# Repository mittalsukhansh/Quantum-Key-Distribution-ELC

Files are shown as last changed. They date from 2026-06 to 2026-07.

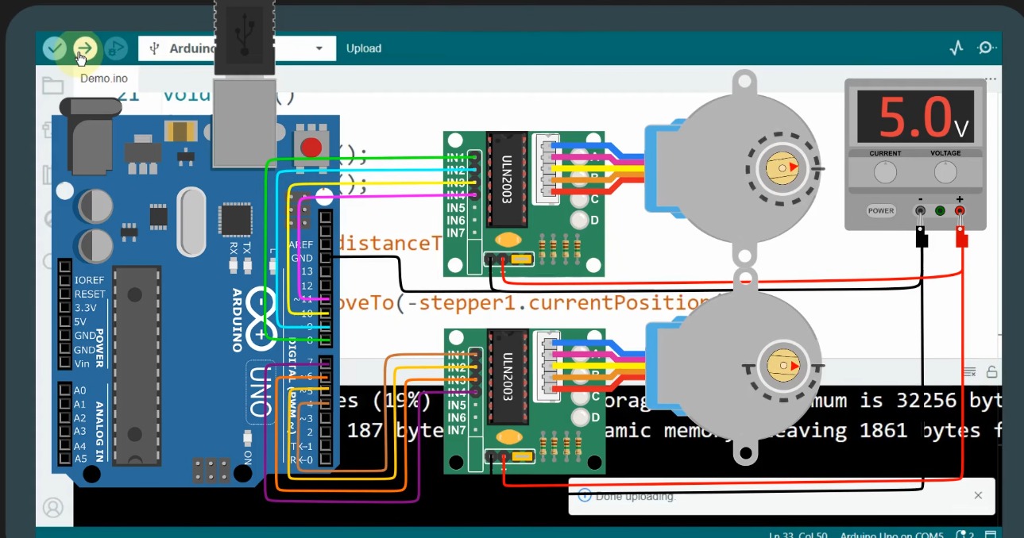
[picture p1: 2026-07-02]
codes/connection_setup.jpeg

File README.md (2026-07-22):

# Quantum-Key-Distribution-ELC

# Low-Cost Quantum Key Distribution (QKD) Simulator using Photonic Communication

**Project 19**

Supervised by: Dr. G.V. Eswara Rao & Dr. Subhrendu Chattopadhyay

Repository: [mittalsukhansh/Quantum-Key-Distribution-ELC](https://github.com/mittalsukhansh/Quantum-Key-Distribution-ELC)

---

## Overview

This project implements a low-cost, hardware-based simulator for **Quantum Key Distribution (QKD)** using photonic (optical) communication. QKD is a method for securely exchanging cryptographic keys using quantum states of light (photons). Its security is guaranteed by the laws of quantum mechanics rather than computational hardness — any attempt at measurement/eavesdropping disturbs the quantum state and introduces detectable errors. This makes QKD **information-theoretically secure**, as opposed to the computationally-secure schemes used in classical cryptography.

## How It Works

**Security Principle:** Any interception changes photon polarization/phase and introduces detectable errors.

**Goal:** Generate symmetric secret keys for encryption with provable detection of eavesdropping.

**QKD Workflow:**
1. Prepare quantum states
2. Transmit photons
3. Measure in chosen bases
4. Sift key
5. Estimate error rate
6. Apply error correction & privacy amplification

**Channel:** Implemented over free-space optical links (photonic communication); sensitive to loss and noise.

## Protocol: BB84

The system implements the **BB84 protocol** (Bennett & Brassard, 1984) — the canonical QKD protocol, using two conjugate polarization bases (rectilinear & diagonal).

1. **State Preparation** – Alice prepares photons in one of four polarization states {0°, 45°, 90°, 135°}, representing bits and bases.
2. **Measurement & Sifting** – Bob measures each photon in a randomly chosen basis; Alice and Bob then publicly compare bases and discard mismatched measurements.
3. **Error Estimation** – A subset of the sifted key is sampled to estimate the Quantum Bit Error Rate (QBER). A high QBER indicates eavesdropping or channel/hardware issues.
4. **Post-Processing** – Error correction (e.g., CASCADE/LDPC) and privacy amplification are applied to produce the final secure key.

**Real-world applications:** Banking & Finance, Government & Defence, Telecom & Backbone Links, Cloud & Data Centres.

## Hardware Architecture

### Transmitter (Alice)
- Laser diode
- Arduino UNO
- LED
- 3D-printed polarizer assembly + stepper motor
- Firmware: [`transmitter.txt`](./transmitter.txt)

### Receiver (Bob)
- Photodiode (BPW32/BPW34)
- 100 V potentiometer
- Resistors
- Op-amp (LM358)
- ESP32 (v1)
- Firmware: [`reciever.c`](./reciever.c)

### Stepper Motors & Polarizers
- Stepper motors rotate 3D-printed polarizer mounts to switch between the four BB84 polarization bases programmatically.
- A custom gear train (motor gear + driven gear on the polarizer holder) provides a precise, repeatable angular step for each basis change.
- Firmware synchronizes motor rotation on the TX side with analyzer rotation on the RX side for every transmitted bit.
- Gear reduction improved angular accuracy beyond the stepper motor's native step resolution, reducing polarization-alignment error.

### Wiring
See [`connection_setup_wire.jpeg`](./connection_setup_wire.jpeg) for the full TX/RX wiring diagram.

## Mechanical Design (3D-Printed Parts)

To reduce cost and improve repeatability, all mechanical parts were custom-designed and 3D-printed using a CAD-driven, iterative design process. Designs are in [`cad/`](./cad).

| Part | Purpose |
|---|---|
| Gears | Transfer precise rotational motion from the stepper motor to the polarizer disc |
| Gear Holders | Keep gears aligned and meshed correctly so rotation stays smooth and slip-free |
| Enclosures (laser & receiver) | Shield the laser diode and photodiode from ambient light and dust, keeping the optical path clean and consistent |
| Base plate & height elevator | Provide a stable, aligned mounting platform for TX/RX components |

Material: **PLA**, chosen for dimensional stability and ease of printing.

## Challenges & Solutions

### Transmitter / Receiver
| Challenge | Solution |
|---|---|
| Unstable timing at low pulse rates causing missed detections | Slowed and fine-tuned code timing so each bit had sufficient read time |
| Laser beam missing the BPW32 detector (alignment drift) | Built a shoebox enclosure with a precisely measured hole to align the beam onto the sensor |
| Receiver unreliable at lower bit rates (timing drift/misreads) | Optimized firmware timing between samples |
| Difficulty identifying a reliable ON/OFF detection threshold under varying light | Repeatedly tested the circuit and manually tuned the threshold using live sensor readings — see [`01_BPW32_ADC_Test.ino`](./01_BPW32_ADC_Test.ino) and [`02_OOK_Detection.ino`](./02_OOK_Detection.ino) |

### 3D Printing
| Challenge | Solution / Notes |
|---|---|
| Lab 3D printer became unreliable mid-build | Reprinted affected parts; adjusted build schedule |
| Achieving tight tolerances | Careful measurement using vernier calipers and screw gauges |
| Material selection | Chose PLA for the best balance of stiffness and printability |

### Stepper Motors & Polarizers
| Challenge | Solution / Result |
|---|---|
| Friction & wear causing step loss | Mechanical adjustments to the gear train |
| Flexible mounts causing misalignment | Improved mounting surface rigidity |
| Steps-per-degree varying under load | Calibration tuning |

**Result:** After mechanical and firmware adjustments, repeatability improved to within acceptable alignment tolerances for experimental QKD demonstration at reduced bit rates.

## Key Learnings

1. **Quantum Cryptography Fundamentals** – How qubits, polarization encoding, and the BB84 protocol combine to enable provably secure key exchange.
2. **Photonics & Hardware Precision** – The importance of exact alignment and timing when working with lasers, polarizers, and photodiodes in a real optical setup.
3. **Mechanical Design & Prototyping** – Practical skills in 3D printing, precise measurement, and iterative design to solve real hardware integration problems.
4. **Embedded Systems Debugging** – Hands-on experience tuning code timing and detection thresholds to make a real-time system work reliably under changing conditions.

## References

- B. A. Forouzan, *Data Communications and Networking*, 5th ed. New York, NY: McGraw-Hill Education, 2013.
- BB84 Protocol
- Photodiode (BPW32/BPW34) datasheet
- Stepper motor datasheet
- Full build documentation: [`QKD-Kit-Development.pdf`](./QKD-Kit-Development.pdf)

---

## Repository Structure
```
.
├── Daily loger/                 # Build/testing logs kept during development
├── cad/                         # 3D-printable part designs (gears, holders, enclosures, base plate)
├── codes/                       # Additional firmware / support code
├── 01_BPW32_ADC_Test.ino        # Arduino sketch: raw ADC test on the BPW32 photodiode
├── 02_OOK_Detection.ino         # Arduino sketch: On-Off Keying (OOK) detection logic
├── reciever.c                   # Receiver (Bob / ESP32) firmware
├── transmitter.txt              # Transmitter (Alice / Arduino UNO) firmware
├── connection_setup_wire.jpeg   # TX/RX wiring diagram
├── Inventory                    # Bill of materials / component inventory
├── QKD-Kit-Development.pdf      # Full project report / build documentation
└── README.md
```

## Getting Started

1. **Bill of materials** – check [`Inventory`](./Inventory) for the full component list.
2. **Wiring** – follow [`connection_setup_wire.jpeg`](./connection_setup_wire.jpeg) to connect the laser/Arduino UNO (TX) and photodiode/ESP32 (RX).
3. **Mechanical build** – 3D-print the parts in [`cad/`](./cad) (PLA recommended) and assemble the gear train, polarizer mounts, and enclosures.
4. **Firmware**
   - Flash [`transmitter.txt`](./transmitter.txt) (rename to `.ino` as needed) to the Arduino UNO for the transmitter.
   - Flash [`reciever.c`](./reciever.c) to the ESP32 for the receiver.
   - Use [`01_BPW32_ADC_Test.ino`](./01_BPW32_ADC_Test.ino) to verify the photodiode is reading correctly before running full detection.
   - Use [`02_OOK_Detection.ino`](./02_OOK_Detection.ino) to test On-Off Keying detection and threshold tuning.
5. **Reference** – see [`QKD-Kit-Development.pdf`](./QKD-Kit-Development.pdf) for the complete build walkthrough.

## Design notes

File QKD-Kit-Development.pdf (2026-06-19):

# Low Cost Quantum Key Distribution (QKD) Simulator using Photonic Communication

Presented By
Dr. G.V. Eswara Rao
&
Dr. Subhrendu Chattopadhyay

# Why Quantum Key Distribution?

- Current Problem
- Classical cryptography relies on computational hardness
- Future quantum computers threaten RSA and ECC
- Sensitive communications require long-term security
- QKD Solution
- Uses principles of quantum mechanics
- Eavesdropping changes quantum states
- Enables secure key exchange with intrusion detection
- Real-World Applications
- Banking and financial networks
- Government communication
- Defense communication systems
- Critical infrastructure
- Data center interconnects

# Quantum Key Distribution (QKD)

### - What is QKD?

- QKD is a secure communication method that uses quantum states to distribute cryptographic keys.

### - Core Principles

- Photons carry information
- Quantum measurement disturbs state
- No-cloning theorem prevents copying
- Eavesdropping becomes detectable

## QKD over Photonic Communication

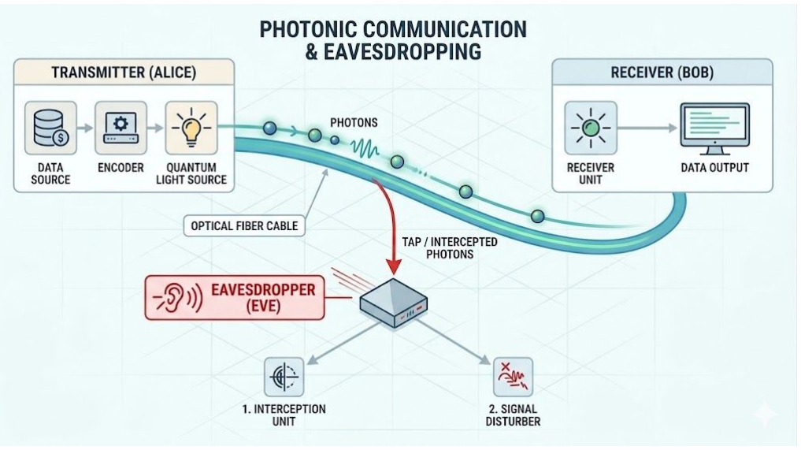
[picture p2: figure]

## QKD over Photonic Communication

### 1. Photons Carry Information

- A photon is a tiny packet of light energy. In quantum communication, photons are used as the “messengers” that carry information from Alice to Bob
- In normal digital communication:
- bits are represented using voltage levels, such as 0 V and 5 V.
- In quantum photonic communication:
- bits are represented using quantum properties of photons,
- especially polarization
- Polarization as Information
- A photon’s electric field can oscillate in different directions.
- For example:
| Polarization | Meaning
- | Horizontal | Bit 0
- VerticalBit 1
- | 45° | Bit 0 in diagonal basis
- | 135° | Bit 1 in diagonal basis
- Thus, information is encoded into photon states.

## QKD over Photonic Communication

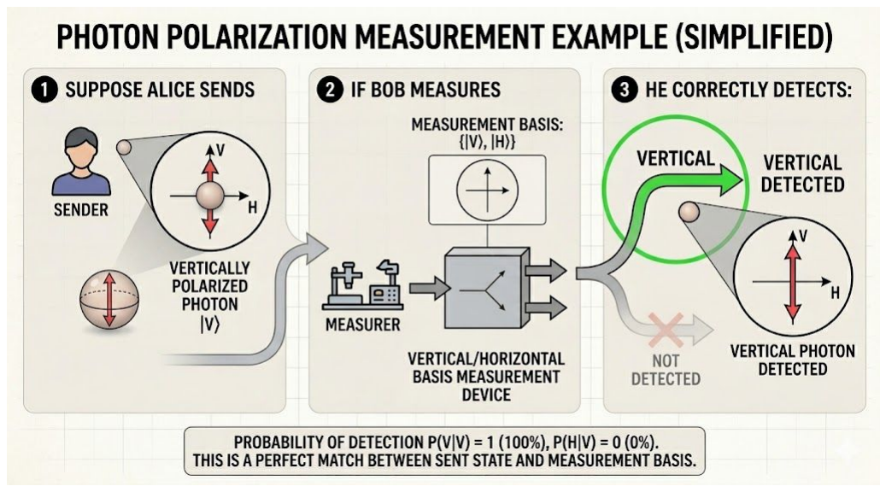
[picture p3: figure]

- But in quantum systems:
measurement itself changes the quantum state
- Example with Polarization Suppose Alice sends: a vertically polarized photon
If Bob measures using:
vertical/horizontal basis, he correctly detects: Vertical

### 2. Quantum Measurement Disturbs the State

- This is one of the most important ideas in quantum mechanics
- In classical systems: you can measure something without changing it

## QKD over Photonic Communication

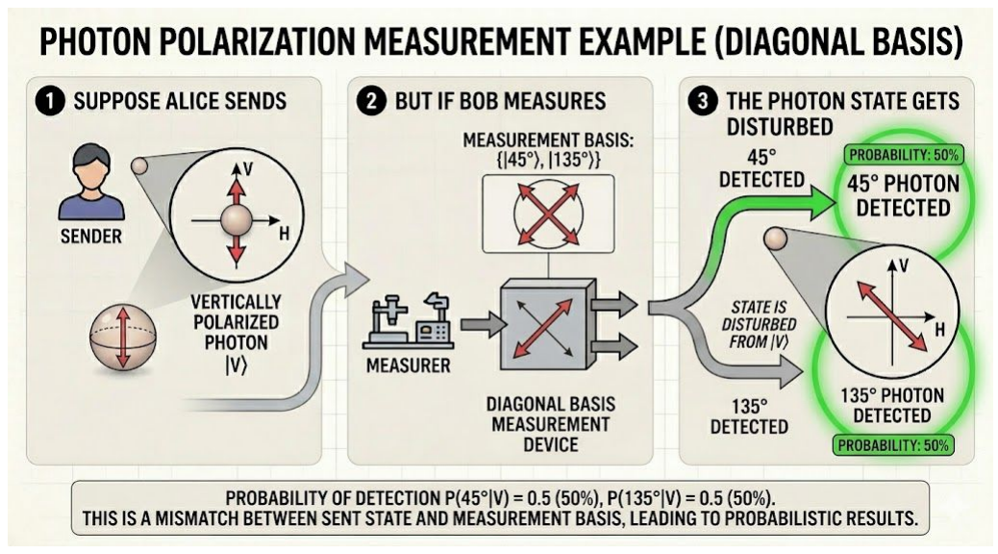
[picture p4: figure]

- But in quantum systems: measurement itself changes the quantum state
- Example with Polarization
Suppose Alice sends: a vertically polarized photon
But if Bob measures using: diagonal basis, the photon state gets disturbed. Now the result becomes
probabilistic:sometimes 45°, sometimes 135°

### 2. Quantum Measurement Disturbs the State

- This is one of the most important ideas in quantum mechanics.
- In classical systems: you can measure something without changing it.

## QKD over Photonic Communication

### 2. Quantum Measurement Disturbs the State

- Why This Happens
- Quantum particles do not always have fixed classical properties before measurement
- Measurement “forces” the system into one of the allowed outcomes
- This process is called: Wave function collapse
- Importance in QKD
- This property creates security. If Eve tries to measure photons: she may choose wrong basis, measurement disturbs the photon, errors appear in Bob’s received bits. Thus:spying changes the communication

## QKD over Photonic Communication

### 3. No-Cloning Theorem Prevents Copying

### - In classical communication: data can be copied perfectly. For Example: copying a file, duplicating

packets, forwarding emails.

### - But in quantum mechanics:

- an unknown quantum state cannot be copied perfectly. This is called: No-Cloning Theorem

## QKD over Photonic Communication

### 3. No-Cloning Theorem Prevents Copying - Intuition

- Suppose Eve intercepts a photon. She wants to: keep a copy and send another identical copy to Bob.
- Quantum mechanics does not allow perfect duplication of an unknown quantum state.
- Why?
- A quantum state may exist in:
- superposition, unknown polarization, probabilistic form.
- And Copying would require: measuring it exactly first. But measurement itself disturbs the state. So perfect copying becomes impossible.

## QKD over Photonic Communication

### 3. No-Cloning Theorem Prevents Copying

### - Security Benefit

- This is a major reason QKD is secure.
- Eve cannot: secretly duplicate photons, store copies, and later analyze them.
- She must interact with the original photon, which introduces detectable errors..

## QKD over Photonic Communication

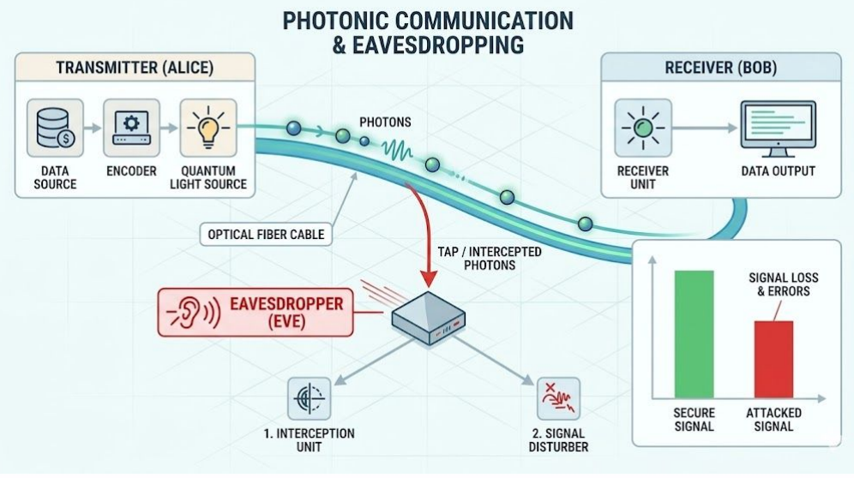
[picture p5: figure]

## QKD over Photonic Communication

Spying leaves evidence.
- How Eve Causes Errors: Suppose Alice sends Vertical polarization and Eve intercepts it. But Eve does not know the correct basis
- | Case 1: Eve Chooses Correct Basis: | She measures correctly. No error introduced.
- | Case 2: Eve Chooses Wrong Basis: | Measurement disturbs photon state.
- When Bob later measures: he may get wrong result.
- Thus: error rate increases.
- Quantum Bit Error Rate (QBER): Alice and Bob compare a small subset of bits publicly. If too many mismatches occur: they conclude: Possible eavesdropping detected
- | Example: | Transmission | Error Rate
| Without Eve: | Normal | Very low
| With Eve: | Intercept-resend attack | High
- Why is this Revolutionary?
- Traditional security depends on: computational difficulty
- Quantum security depends on: laws of physics. That makes QKD fundamentally different from classical cryptography

# Basics of Photonic Communication

## Photonic/Optical Communication

### - Components:

- Transmitter: LED or Laser source
- Channel: Optical fiber or free-space optical link
- Receiver: Photodiode (PIN/APD) converts light to electrical signals
- Signal processing and decoding

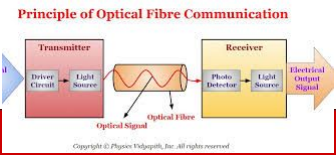
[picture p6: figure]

## Signal Processing in Photonic Communication?

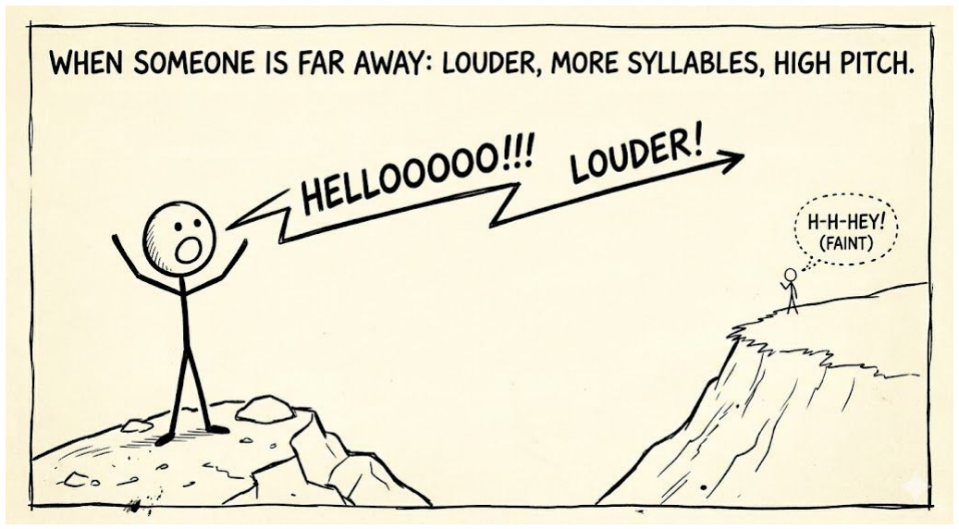
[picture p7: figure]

Think if someone is far away. What do you do? You use modulation and coding. What type of modulation is used in this figure?

## Photonic/Optical Communication

### - How Information is carried:

- Digital encoding to increase data rate.
- Analogue modulation to avoid fading

# Why Coding in Communication?

### - Coding Schemes allows more data embedding in each signal element. Same as use of “more

syllables”.

### - Schemes:

- NRZ
- RZ
- Manchester …

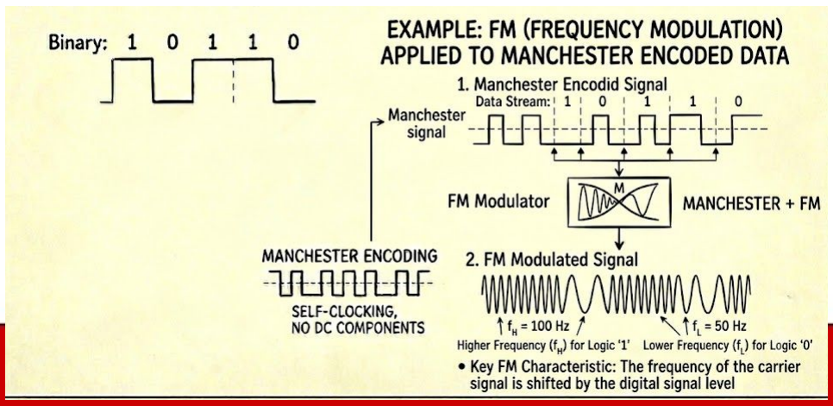
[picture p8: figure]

# Why Coding in Communication?

### - Coding Schemes allows more data embedding in each signal element. Same as use of “more

syllables”.

### - Schemes:

- NRZ
- RZ
- Manchester …

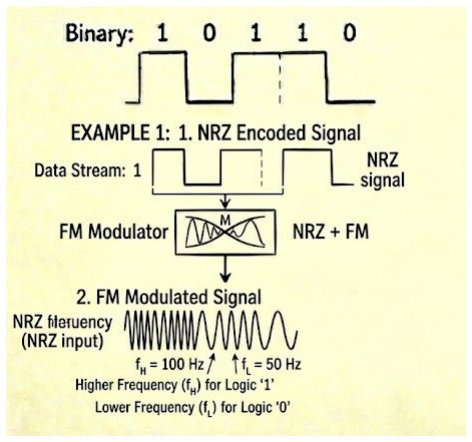
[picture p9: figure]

# Coding Schemes in Photonics

Scheme | Main Advantage | Main Disadvantage
NRZ | Minimum bandwidth | Poor synchronization
RZ | Better synchronization | Higher bandwidth required
Manchester | Self-clocking | Highest bandwidth required

## Why Modulation in Communication?

### - Allows smaller antennas - Enables long-distance transmission - Prevents signal mixing (interference) - Improves signal quality and reduces noise - Supports multiplexing - Efficient use of bandwidth

L≈ (λ/4) = (c/4f)
where: L = antenna length; λ = wavelength; c = speed of light; f = frequency

## Why Modulation in Communication?

### - Allows smaller antennas - Enables long-distance transmission - Prevents signal mixing (interference) - Improves signal quality and reduces noise - Supports multiplexing - Efficient use of bandwidth

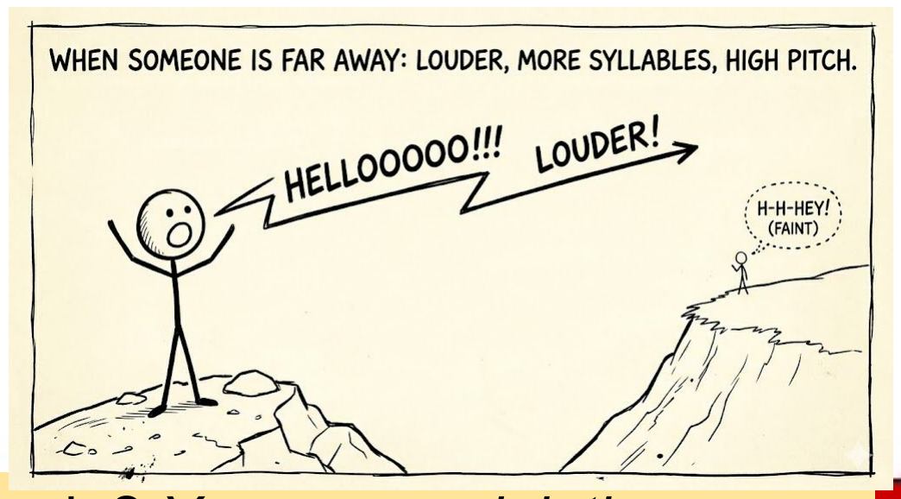
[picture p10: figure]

Think if someone is far away. What do you do? You use modulation. What type of modulation is used in this figure?

## Modulation and Coding Scheme

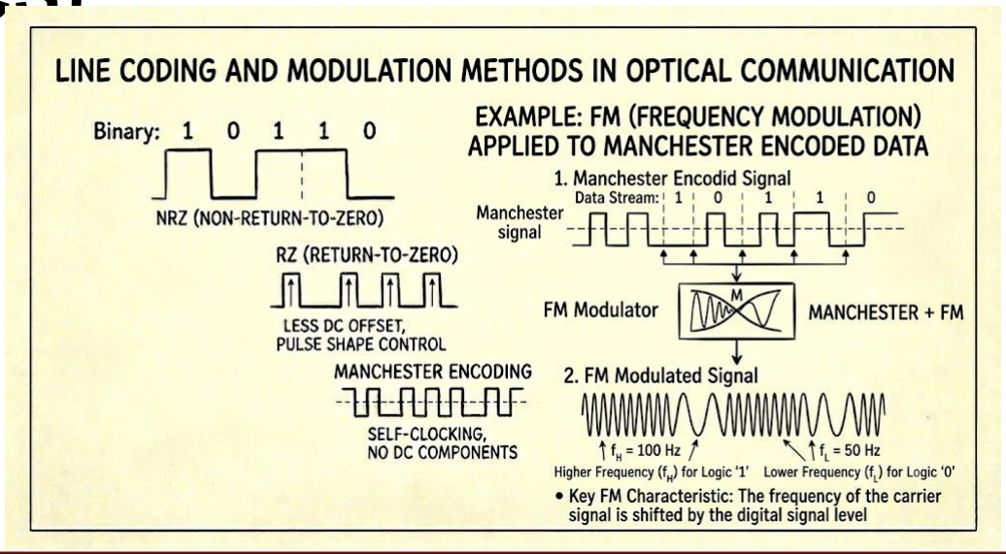
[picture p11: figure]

# (MCS)

## Photonic/Optical Communication

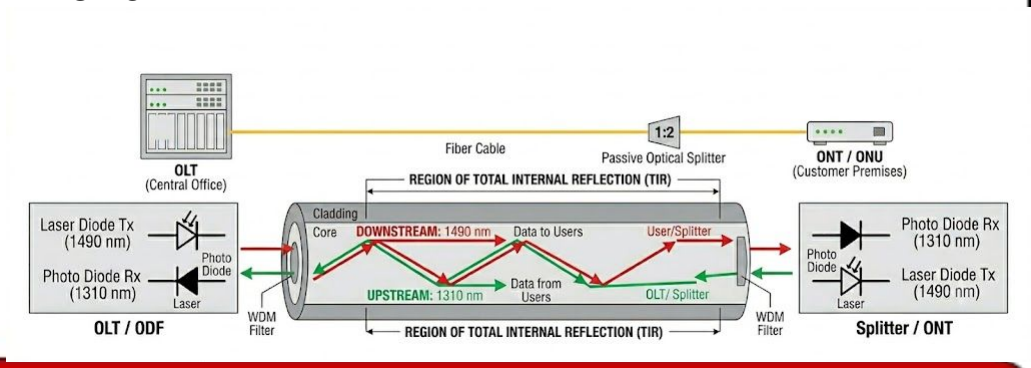
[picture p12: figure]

https://www.cisco.com/c/en/us/products/collateral/interfaces-modules/transceiver-modules/datasheet-c 78-736392.html (https://www.cisco.com/c/en/us/products/collateral/interfaces-modules/transceiver-modules/datasheet-c78-736392.html)

- Modulation: Intensity, Phase, Frequency
- Digital data represented by optical pulses

### - Modulation:

- Wavelength Division Multiplexing (WDM) ⇒ FDM
- Used in GPON Gateways for Duplex communication
- | TX: 1490 nm; | Rx: 1310 nm

# Basics of TCP/IP Stack

# TCP/IP Protocol Stack

https://en.wikipedia.org/wiki/Internet_protocol_suite

- The TCP/IP protocol stack (also known as the Internet Protocol Suite) is the conceptual framework and set of rules that allows computers to communicate over a network, including the global Internet.
- It breaks the complex process of moving data across the world into a modular, 4-layer stack. As data moves down the stack on the sender's side, each layer adds its own formatting header (encapsulation). When it arrives at the receiver, the process reverses (decapsulation).

+----------------------+
| Application | |
| HTTP, MQTT, DNS | |
+----------------------+
| Transport | |
| TCP, UDP | |
+----------------------+
| Internet | |
| IP, ICMP | |
+----------------------+
| Data Link | |
| 802.11 MAC, Ethernet |
+----------------------+
| Physical | |
| RF, Fiber, Copper | |
+----------------------+

# TCP/IP Protocol Stack

Development of full stack will be difficult.

Therefore, we’ll create a
smaller stack like this.

Components required:

+---------------------------------+
| Application Layer | |
| Text / Files / Commands | |
+---------------------------------+
| Data Link Layer | |
| Framing + CRC + ACK | |
+---------------------------------+
| Physical Layer | |
| NRZ encoding, | |
| OOK modulation, | |
| TX: Laser Driver, | |
| RX: BPW32 + TIA | |
+---------------------------------+

# Our Goal

## Our Setup: Hardware Requirement

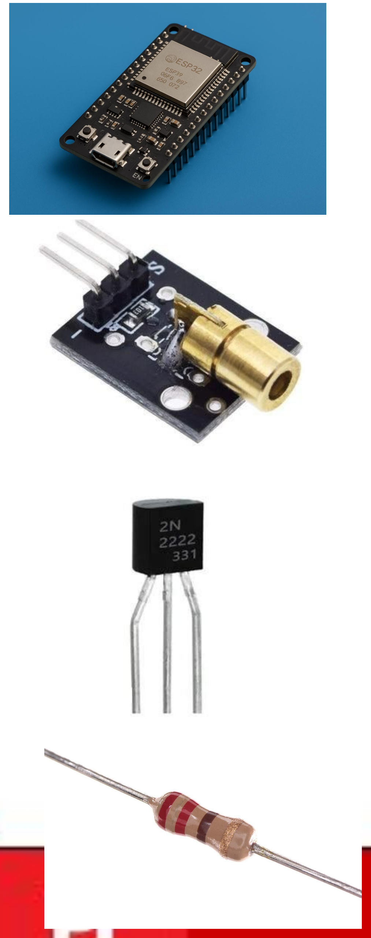
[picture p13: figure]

Components required: for TX

ESP32 DevKit → Controller
Laser Diode Module → Optical transmitter
NPN Transistor (2N2222/BC547) → Laser driver 220Ω–1kΩ Resistor → Transistor bias Breadboard/PCB → Prototyping
Power Supply (5V) → Laser power

## Our Setup: Hardware Requirement

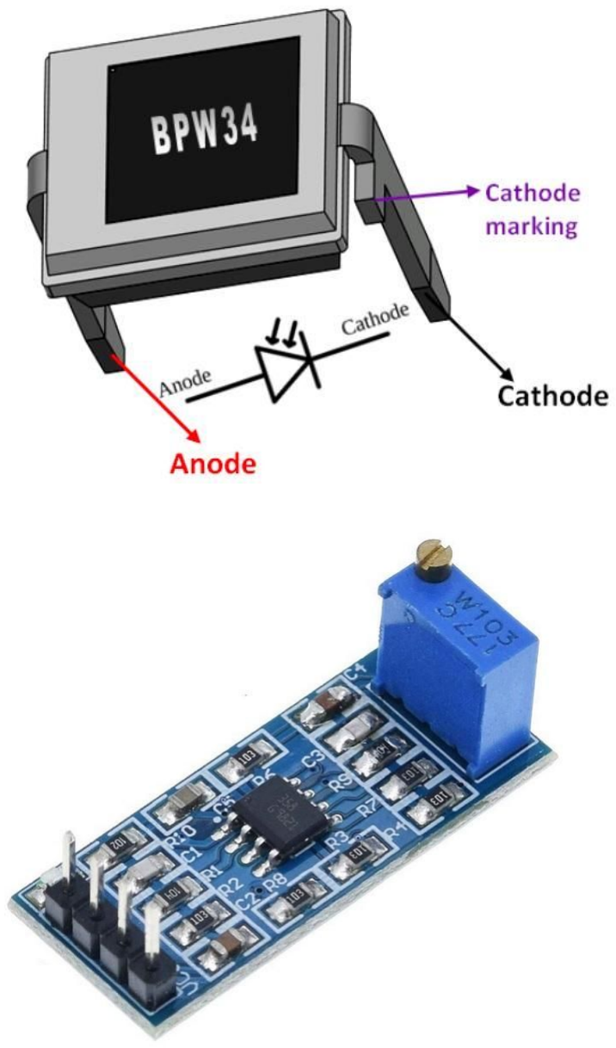
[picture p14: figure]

Components required: for RX

ESP32 DevKit → Controller
Breadboard/PCB → Prototyping Power Supply (5V) → Laser power
BPW32 Photodiode → Optical detector
LM393 Comparator → Digital slicing
Feedback Resistors (100kΩ–1MΩ) → Gain setting Capacitors (10pF–100nF) → Stability/filtering

## Our Setup: Software Requirement

Complete TX Call Flow

app_send_text()
│
└── mac_send()
│
├── create_frame()
├── append_crc()
│
└── phy_send_frame()
│
├── NRZ_encode()
├── ook_modulate()
│
└── laser_set()

+---------------------------------+
| Application Layer | |
| Text / Files / Commands | |
+---------------------------------+
| Data Link Layer | |
| Framing + CRC + ACK | |
+---------------------------------+
| Physical Layer | |
| NRZ encoding, | |
| OOK modulation, | |
| TX: Laser Driver, | |
| RX: BPW32 + TIA | |
+---------------------------------+

# TCP/IP Protocol Stack

Complete RX Call Flow

application_receive()
▲
└─ mac_receive()
│
├── crc_verify()
├── extract_payload()
▲
└── phy_receive_frame()
│
├── NRZ_decode()
├── ook_demodulate()
▲
└── bpw32_read()

+---------------------------------+
| Application Layer | |
| Text / Files / Commands | |
+---------------------------------+
| Data Link Layer | |
| Framing + CRC + ACK | |
+---------------------------------+
| Physical Layer | |
| NRZ encoding, | |
| OOK modulation, | |
| TX: Laser Driver, | |
| RX: BPW32 + TIA | |
+---------------------------------+

# TCP/IP Protocol Stack

+------------------------+
| Application Layer | |
| application_receive() | |
+------------------------+
| MAC Layer | |
| mac_receive() | |
| ├─ crc_verify() | |
| └─ extract_payload() | |
+------------------------+
| PHY Layer | |
| phy_receive_frame() | |
| ├─ manchester_decode() | | └─ ook_demodulate() |
+------------------------+
| Driver Layer | |
| bpw32_read() | |
+------------------------+
| Hardware | |
| BPW32 + TIA | |
+------------------------+

+------------------------+
| Application Layer | |
| application_send() | |
+------------------------+
| MAC Layer | |
| mac_send() | |
| ├─ create_header() | |
| ├─ add_payload() | |
| ├─ calculate_crc() | |
| └─ add_preamble() | |
+------------------------+
| PHY Layer | |
| phy_send_frame() | |
| ├─ manchester_encode() |
| ├─ ook_modulate() | |
| └─ symbol_timing() | |
+------------------------+
| Driver Layer | |
| laser_set() | |
| laser_enable() | |
| timer_start() | |
+------------------------+
| Hardware | |
| Laser Driver Circuit | |
| Laser Diode | |
+------------------------+
TX | RX

# Important Tutorials

# Tutorials

- Lec05: Digital Communication for Optical Communication
- https://www.youtube.com/watch?v=j0c9xHWtATo
- Arduino Photodiode Light Sensor (BPW34) Circuit &amp; Code Example. Arduino Photodiode Circuit Example For light intensity measurement (BPW34)"
- https://deepbluembedded.com/arduino-photodiode-light-sensor-bpw34-circuit-code-example/ (https://deepbluembedded.com/arduino-photodiode-light-sensor-bpw34-circuit-code-example/)
- Li - fi communication system using ON OFF Keying (OOK)
- https://www.youtube.com/watch?v=Aj9jUR7Xog8
- 28BYJ-48 Stepper Motor with ULN2003 & Arduino | Full Step vs
Half Step
- https://www.youtube.com/watch?v=uJriwdnPUD4
- Quantum cryptography: The BB 84 protocol (U3-02-03)
- https://www.youtube.com/watch?v=2kdRuqvIaww

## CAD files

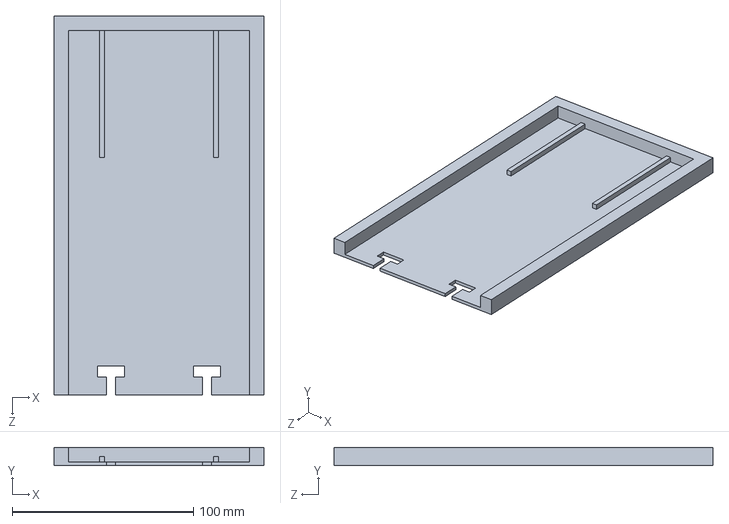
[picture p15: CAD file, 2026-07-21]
cad/Base Plate/Base tray part 1.SLDPRT
116.0 x 10.0 x 209.2 mm

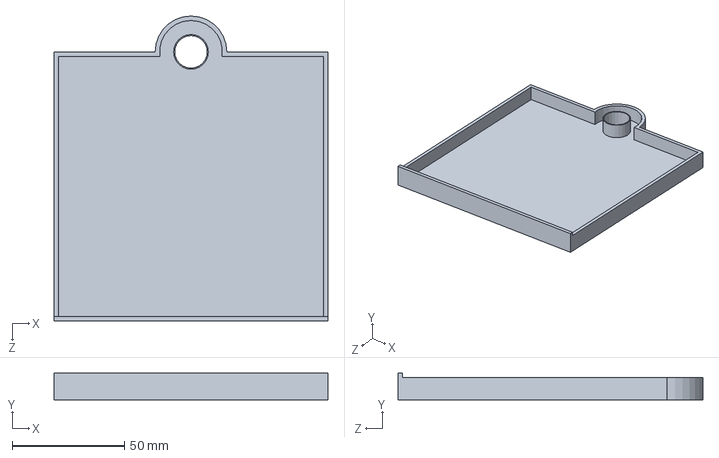
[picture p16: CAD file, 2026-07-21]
cad/gear/Gear holder2.SLDPRT
122.0 x 12.0 x 136.0 mm

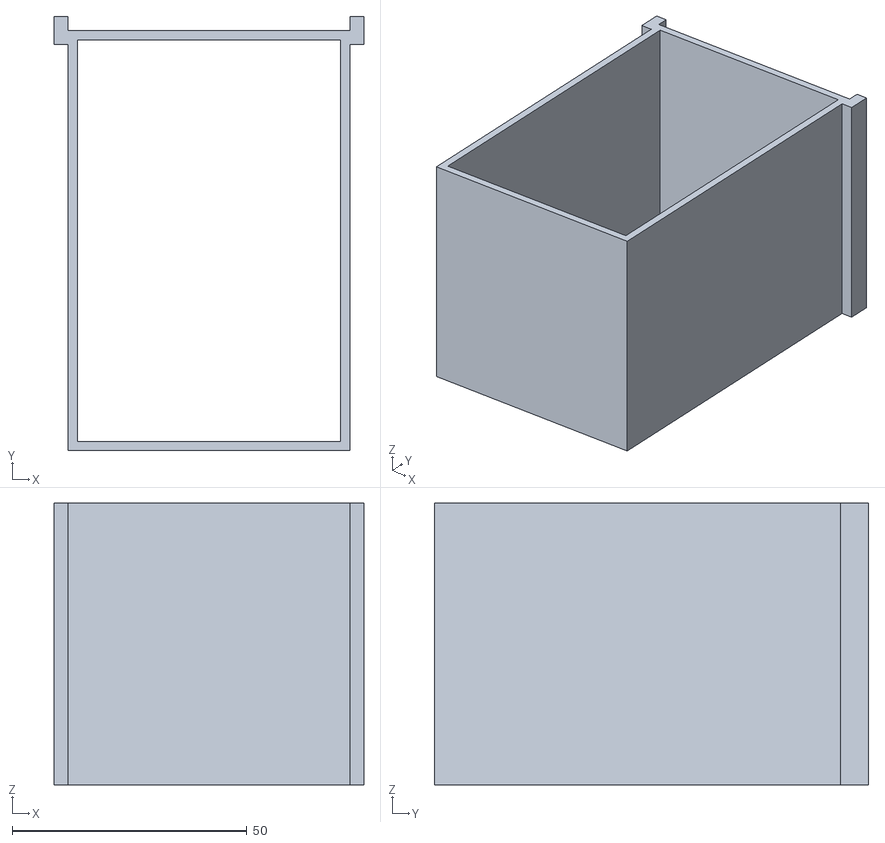
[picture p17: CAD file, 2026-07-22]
cad/Height adjusters/Reciever height stl.STL
66.0 x 92.5 x 60.0

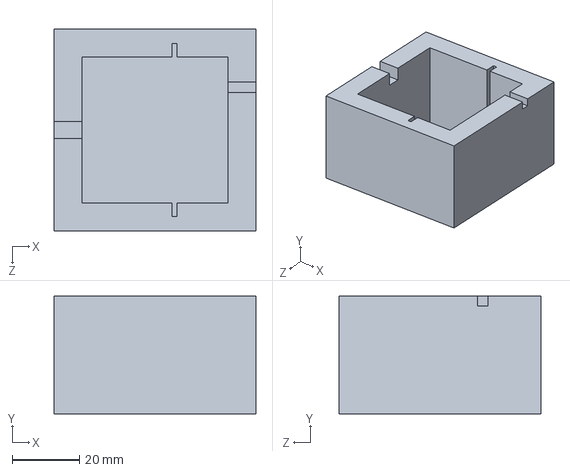
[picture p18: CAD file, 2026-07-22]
cad/LED AND RECIEVER/Part2.SLDPRT
60.0 x 35.0 x 60.0 mm

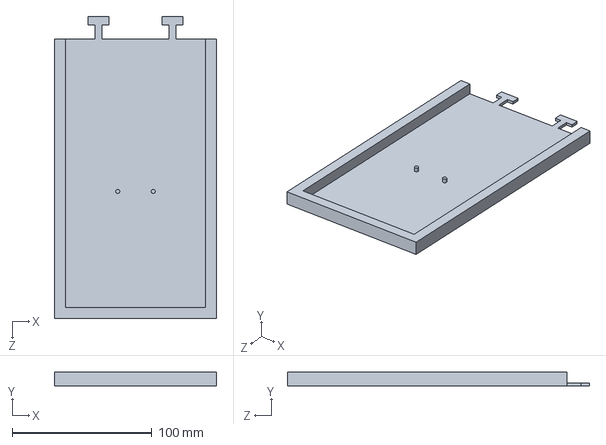
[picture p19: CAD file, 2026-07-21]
cad/Base Plate/base tray 2.SLDPRT
116.0 x 10.0 x 216.0 mm

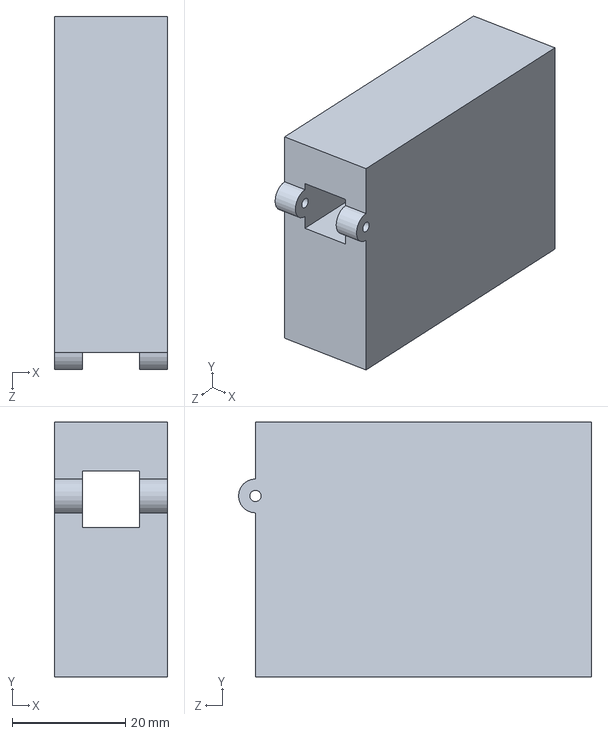
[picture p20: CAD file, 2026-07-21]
cad/LED AND RECIEVER/Laser box final.SLDPRT
20.0 x 45.0 x 62.4 mm

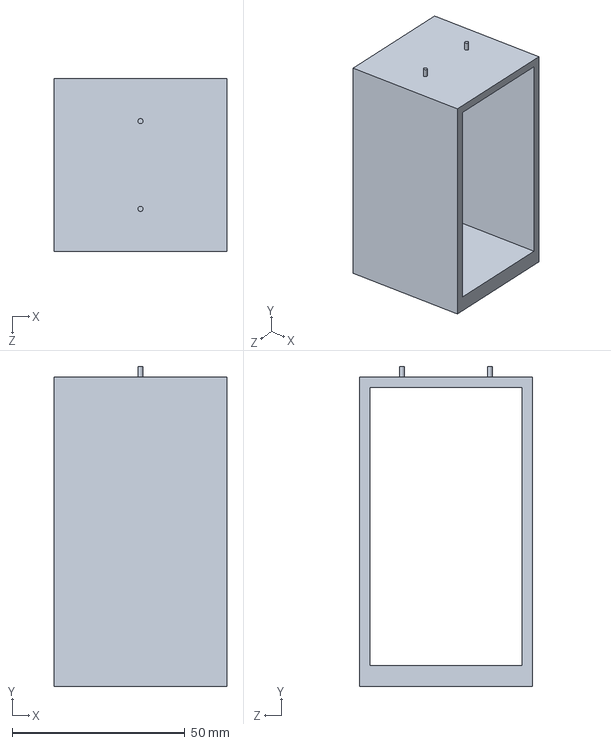
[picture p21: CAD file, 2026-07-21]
cad/Height adjusters/laser box height.SLDPRT
50.0 x 92.5 x 50.0 mm

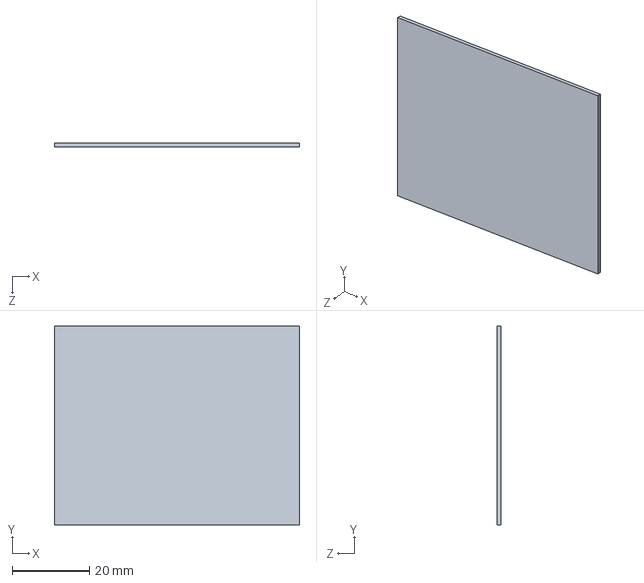
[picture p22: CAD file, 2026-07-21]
cad/LED AND RECIEVER/Receiver pcb.SLDPRT
63.3 x 51.3 x 1.00 mm

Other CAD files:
cad/Height adjusters/Reciever height.SLDPRT
cad/LED AND RECIEVER/top.SLDPRT
cad/Base Plate/Base tray part 1.STL
cad/Base Plate/base tray 2.STL
cad/Height adjusters/laser box height.STL
cad/gear/16 T.f3d
cad/gear/72 T.f3d
cad/gear/Gear holder2.STL

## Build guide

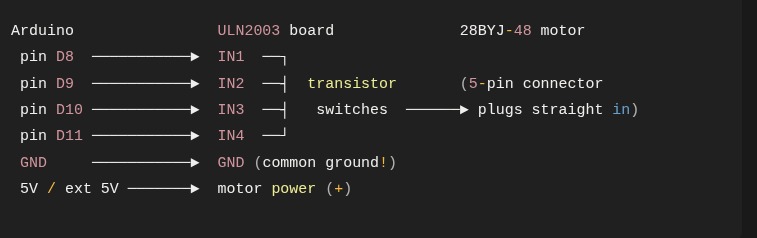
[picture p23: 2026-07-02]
connection_setup_wire.jpeg

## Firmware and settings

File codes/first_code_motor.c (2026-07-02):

#include <AccelStepper.h>

// Motor 1
AccelStepper stepper1(
  AccelStepper::HALF4WIRE,
  4, 6, 5, 7
);

// Motor 2
AccelStepper stepper2(
  AccelStepper::HALF4WIRE,
  8, 10, 9, 11
);

// BB84 positions
const long POS_0   = 0;
const long POS_45  = 256;
const long POS_90  = 512;
const long POS_135 = 768;

void moveMotor1(long target)
{
  stepper1.moveTo(target);

  while(stepper1.distanceToGo() != 0)
  {
    stepper1.run();
  }
}

void moveMotor2(long target)
{
  stepper2.moveTo(target);

  while(stepper2.distanceToGo() != 0)
  {
    stepper2.run();
  }
}

void setup()
{
  stepper1.setMaxSpeed(800);
  stepper1.setAcceleration(400);

  stepper2.setMaxSpeed(800);
  stepper2.setAcceleration(400);
}

void loop()
{
  // Example sequence

  moveMotor1(POS_0);
  delay(1000);

  moveMotor1(POS_45);
  delay(1000);

  moveMotor1(POS_90);
  delay(1000);

  moveMotor1(POS_135);
  delay(1000);

  moveMotor2(POS_0);
  delay(1000);

  moveMotor2(POS_45);
  delay(1000);

  moveMotor2(POS_90);
  delay(1000);

  moveMotor2(POS_135);
  delay(1000);
}

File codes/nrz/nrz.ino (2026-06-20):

// transmitter nrz

int ledPin = 13;
int bitTime = 500;

void setup() {
  pinMode(ledPin, OUTPUT);
  Serial.begin(9600);

  Serial.println("Enter bit string:");
}

void sendNRZBit(char bit) {
  if (bit == '1') {
    digitalWrite(ledPin, HIGH);
  } else {
    digitalWrite(ledPin, LOW);
  }

  delay(bitTime);
}

void loop() {
  if (Serial.available()) {

    String data = Serial.readStringUntil('\n');

    Serial.print("Sending: ");
    Serial.println(data);

    for (int i = 0; i < data.length(); i++) {

      if (data[i] == '0' || data[i] == '1') {
        sendNRZBit(data[i]);
      }

    }

    digitalWrite(ledPin, LOW);
  }
}

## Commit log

2026-06-18 Added BPW32 ADC test
2026-06-19 Second stage
2026-06-21 Add Manchester RX implementation for Arduino
2026-07-02 connection_setup for motor
2026-07-02 wire connection setup for motor
2026-07-08 Add v2_speedcheck for VLC Receiver on ESP32
